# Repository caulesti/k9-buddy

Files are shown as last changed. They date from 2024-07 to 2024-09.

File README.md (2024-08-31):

# K9-Buddy
K9-Buddy is an open-source quadruped robot designed to promote STEAM education and provide a solid foundation for competing in robotics events. Notable for its low cost, K9-Buddy is accessible to both students and robotics enthusiasts.
<p align="center">
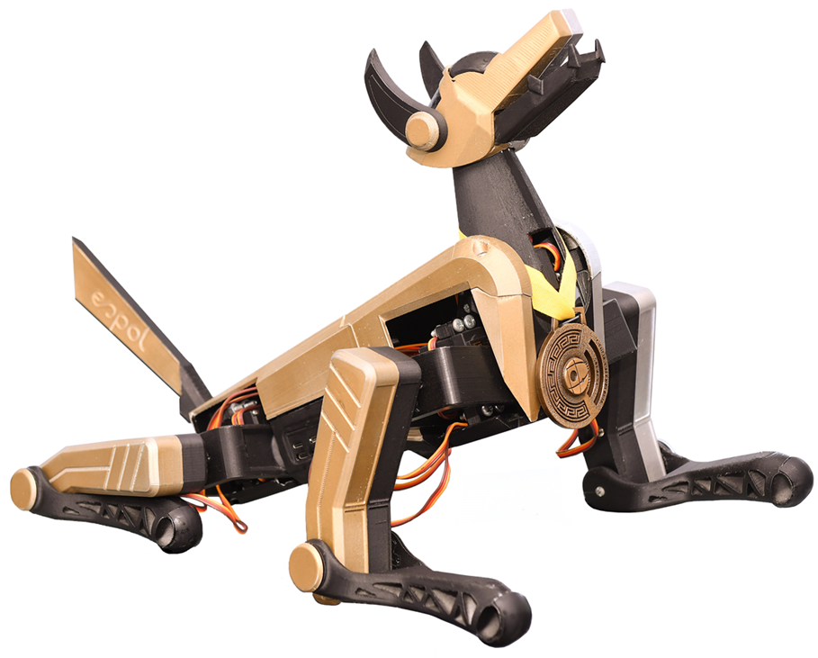
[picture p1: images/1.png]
K9-Buddy
  
</p>

### Environment Setup
1. Update the System
   
Open a terminal and run the following commands to update the package list and upgrade the installed packages to their latest versions:
```
sudo apt-get update
sudo apt-get upgrade
```
2. Install Python and Pip 
```
sudo apt-get install -y python3
sudo apt-get install -y python3-pip
```
3. Enable I2C and SSH services
   
Open the Raspberry Pi configuration menu
```
sudo raspi-config
```
Navigate to Interfacing Options > I2C and select Yes to enable I2C.
Navigate to Interfacing Options > SSH and select Yes to enable SSH.
Restart the Raspberry Pi to apply the changes:
```
sudo reboot
```
4. Install Additional Packages
   
Open a terminal and run the following commands:
```
# Install python-smbus and i2c-tools
sudo apt-get install -y python3-smbus
sudo apt-get install -y i2c-tools

# Verify the I2C connection
sudo i2cdetect -y 1

# Install Adafruit CircuitPython ServoKit
sudo pip3 install adafruit-circuitpython-servokit
```

### Usage
1. Cloning the Repository
```
git clone https://github.com/caulesti/k9-buddy.git
```
2. Grant permissions to the script
```
chmod +x k9-buddy/software/k9_buddy.py
```
3. Execution
```
python3 k9-buddy/software/k9_buddy.py
```

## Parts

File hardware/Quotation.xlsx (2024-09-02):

Component | Reference Supplier | Quantity | Unit price | Total price | Link
PiSugar S Plus | Amazon | 1 | $27.59 | $27.59 | https://www.amazon.com/-/es/dp/B097RCFHD2/ref=emc_b_5_t
Raspberry Pi 4 Model B | Amazon | 1 | $189.99 | $189.99
PCA9685 | Amazon | 1 | $20.74 | $20.74 | Amazon.com: 2327 - Raspberry Pi PWM Servo Hat Development Board : Electrónica (https://www.amazon.com/-/es/2327-Raspberry-Servo-Development-Board/dp/B00SI1SPHS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)
Step Down | Amazon | 1 | $10.99 | $10.99 | Amazon.com: ACEIRMC 3 unidades 20A 300W CC CV módulo de paso hacia abajo ajustable DC 6-40V a 1.2-36V regulador de voltaje Buck Converter módulo de fuente de alimentación de corriente constante : Electrónica (https://www.amazon.com/-/es/Aceirmc-convertidor-corriente-protecci%C3%B3n-cortocircuitos/dp/B099S2VQ2Q)
LiPo 2200mAh 7.4v | Amazon | 1 | $10.00 | $10.00 | Amazon.com: HRB 2 baterías 2S Lipo 7.4V 2200mAh RC LiPo con enchufe TR compatible con RC Car Truck Quadcopter Avión, Helicóptero Barco : Juguetes y Juegos (https://www.amazon.com/bater%C3%ADas-2200mAh-compatible-Quadcopter-Helic%C3%B3ptero/dp/B088QX6SXQ)
Servos MG90S | Amazon | 3 | $4.80 | $14.40 | Amazon.com: DiGiYes Paquete de 2 micro servomotores MG90S con engranaje de metal 9G para helicóptero, avión, barco, robot inteligente, controles de automóvil (ángulo de control de 360 grados) : Juguetes y Juegos (https://www.amazon.com/-/es/servomotores-MG90S-engranaje-helic%C3%B3ptero-inteligente/dp/B0BHYH7MQK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)
Servos MG995 | Amazon | 13 | $7.50 | $97.50 | https://www.amazon.com/-/es/servomotores-engranaje-velocidad-inteligente-helic%C3%B3ptero/dp/B0C3CWSCV1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
Total |  |  |  | $371.21

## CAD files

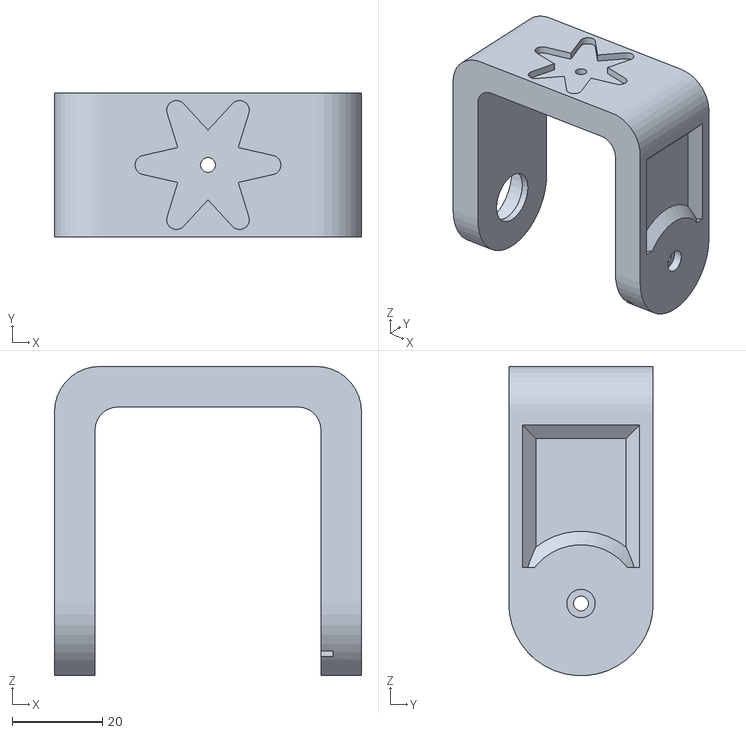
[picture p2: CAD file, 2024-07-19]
mechanical_design/stl_models/Hombro Izquierdo.STL
68.0 x 32.0 x 68.5

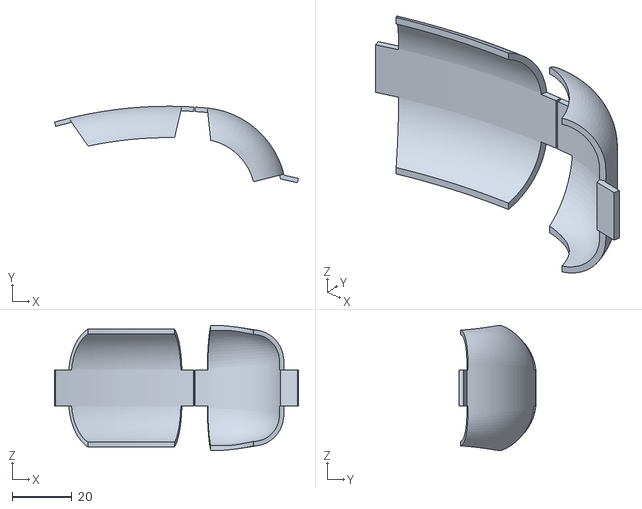
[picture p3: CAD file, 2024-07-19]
mechanical_design/stl_models/Visor.STL
81.7 x 25.6 x 41.8

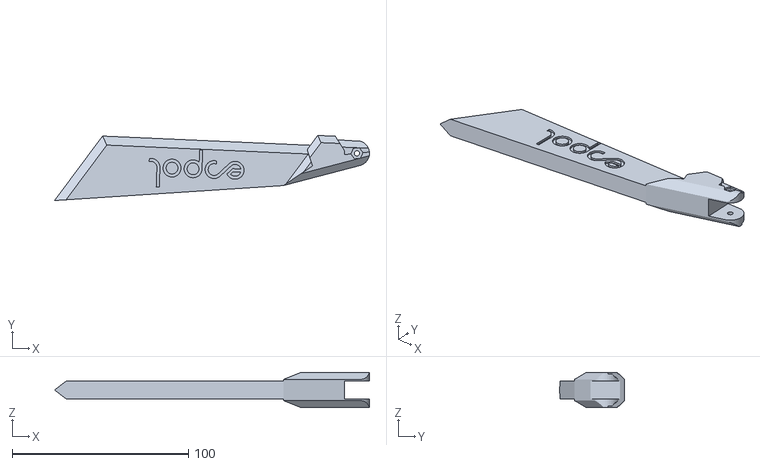
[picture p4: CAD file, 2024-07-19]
mechanical_design/stl_models/Cola.STL
178.9 x 37.0 x 20.0

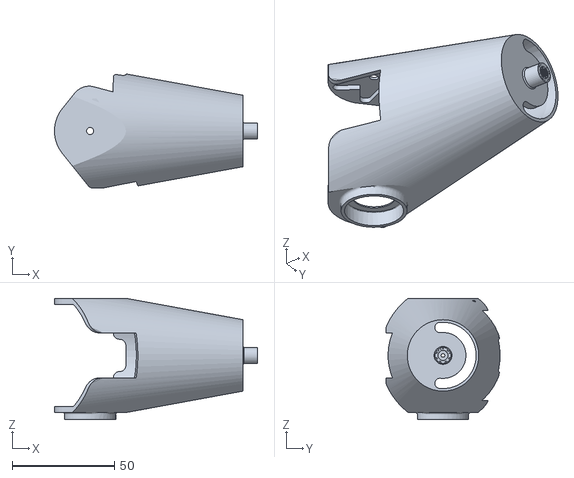
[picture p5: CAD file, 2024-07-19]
mechanical_design/stl_models/Cuello.STL
99.5 x 56.0 x 59.5

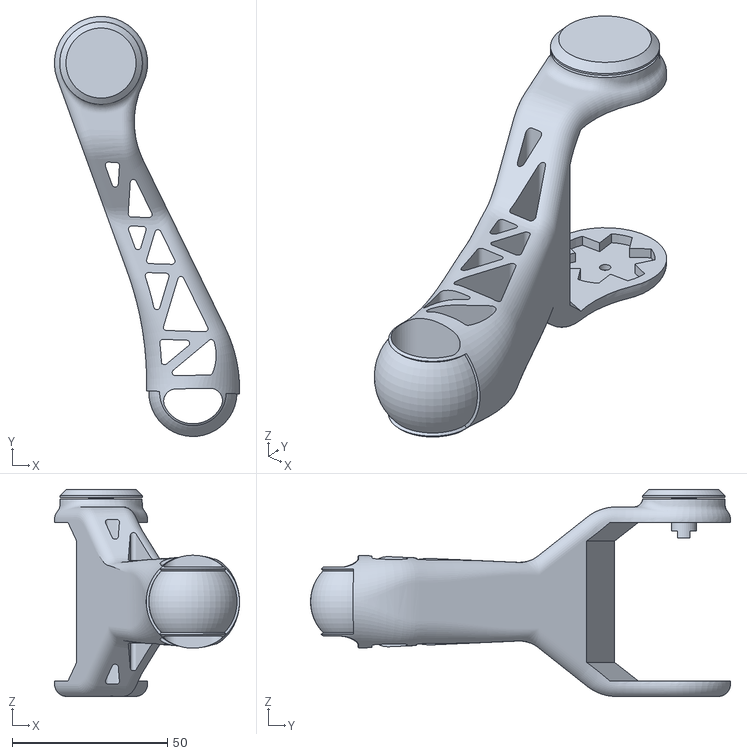
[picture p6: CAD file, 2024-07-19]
mechanical_design/stl_models/Pierna Inferior Derecha.STL
59.6 x 135.1 x 66.6

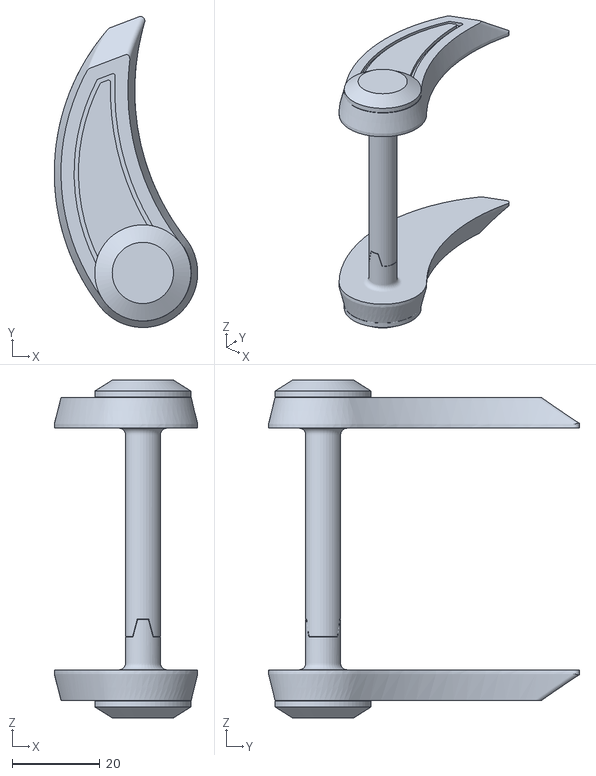
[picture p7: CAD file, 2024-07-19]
mechanical_design/stl_models/Orejas.STL
32.8 x 71.1 x 77.2

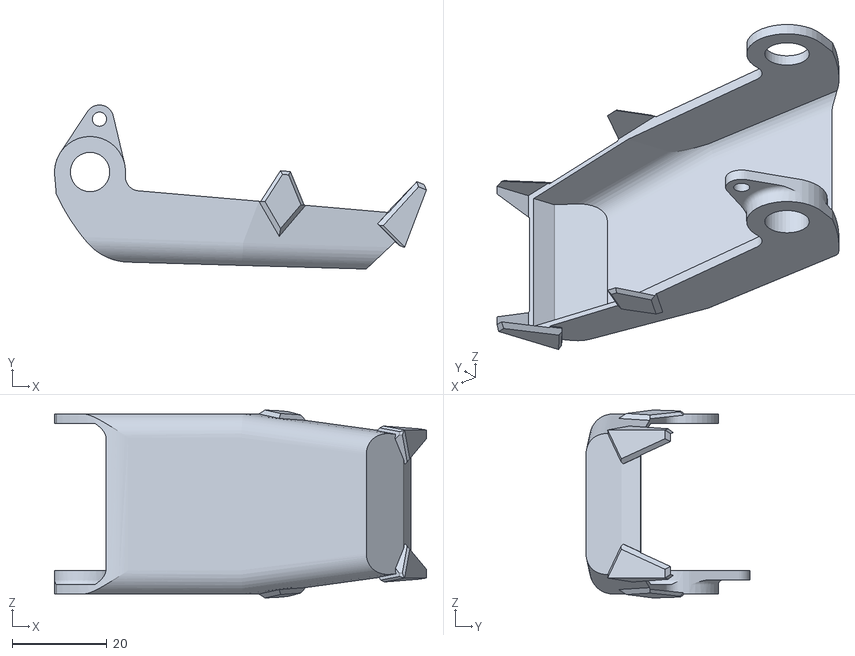
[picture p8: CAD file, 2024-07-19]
mechanical_design/stl_models/Mandibula.STL
78.5 x 34.6 x 39.7

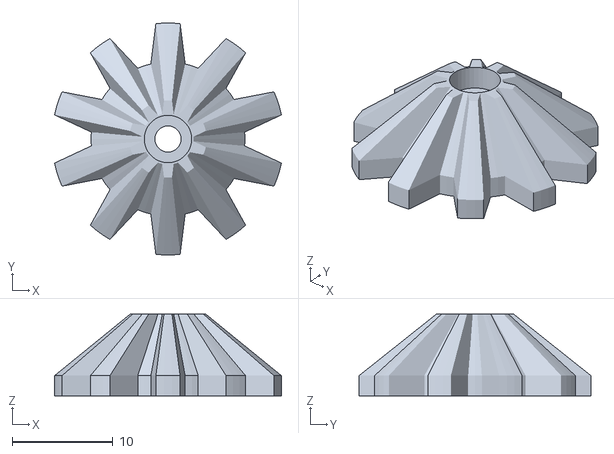
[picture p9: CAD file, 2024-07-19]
mechanical_design/stl_models/Engranaje Conico .STL
22.5 x 23.0 x 8.10

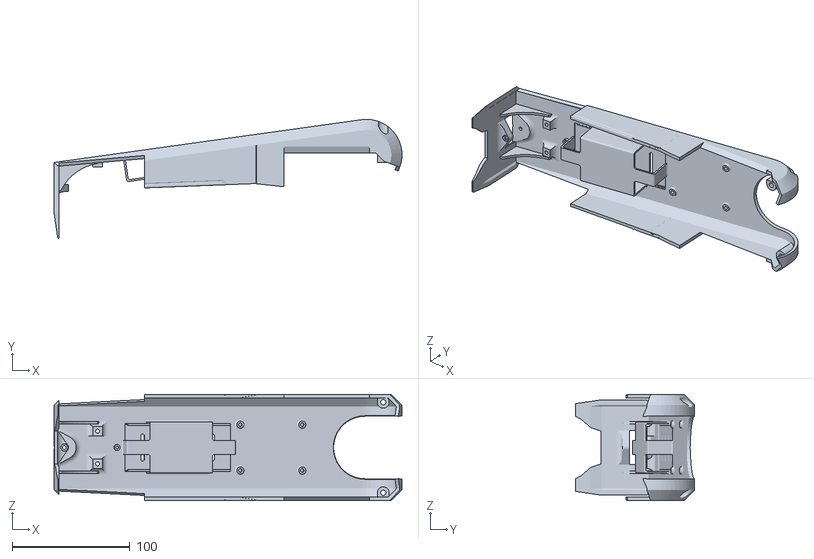
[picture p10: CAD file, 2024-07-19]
mechanical_design/stl_models/Cuerpo Superior.STL
295.0 x 101.1 x 90.0

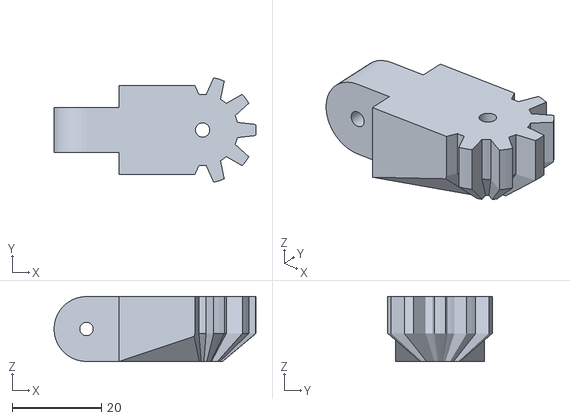
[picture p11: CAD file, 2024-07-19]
mechanical_design/stl_models/Union Cola.STL
45.4 x 23.5 x 14.6

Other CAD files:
mechanical_design/stl_models/Hombro Derecho.STL
mechanical_design/stl_models/Pierna Inferior Izquierda.STL

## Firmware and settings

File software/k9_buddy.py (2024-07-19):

#!/usr/bin/env python
# -*- coding: utf-8 -*-

# sudo apt-get install -y python-smbus
# sudo apt-get install -y i2c-tools
# sudo i2cdetect -y 1
# sudo pip3 install adafruit-circuitpython-servokit
  
#Libraries
import RPi.GPIO as GPIO
import time    
from adafruit_servokit import ServoKit 
import math  
#Constants
nbPCAServo=16
#Parameters
MIN_IMP  =[500, 500, 500, 500, 500, 500, 500, 500, 500, 500, 500, 500, 500, 500, 500, 500]
MAX_IMP  =[2500, 2500, 2500, 2500, 2500, 2500, 2500, 2500, 2500, 2500, 2500, 2500, 2500, 2500, 2500, 2500]
MIN_ANG  =[0, 0, 0, 0, 0, 0, 0, 0, 0, 0, 0, 0, 0, 0, 0, 0]
MAX_ANG  =[180, 180, 180, 180, 180, 180, 180, 180, 180, 180, 180, 180, 180, 180, 180, 180]
#Referencia
"""
Mi colocar el valor de la boca cerrada
Ce colocar el valor de la cabeza a la altura media
Cr colocar el valor de la cabeza centrada
"""
servoref =[60 ,80   ,-9  , 90 , 35  ,95  , 47   ,90 , 60  ,80  ,145  , 20 , 15 , 95 , 150, 130]
#PIN      [0  , 1   , 2  , 3  , 4   ,5   , 6    , 7 , 8   , 9  ,10   , 11 , 12  , 13 , 14 , 15 ]
#Nombres  [TD ,FD   , PD , Sc , RD  , HD , ED   , Cr, EI  , HI ,RI   , Mi , PI  , FI , Ce , TI ]
#Objects
pca = ServoKit(channels=16)
#Variables
pitch=0
roll=0
c=[0.0,0.0,0.0,0.0]
d=[0.0,0.0,0.0,0.0]
x=[0.0,0.0,0.0,0.0]
y=[0.0,0.0,0.0,0.0]
z=[0.0,0.0,0.0,0.0]
fo=[0.0,0.0,0.0,0.0]
fn=[0.0,0.0,0.0,0.0]
angle=[0,0,0,0,0,0,0,0,0,0,0,0,0,0,0,0]
#Modificar con las dimensiones del modelo físico
c[0] = c[1] = c[2] = c[3] = 186.81 #mm
fo[0] = fo[1] = fo[2] = fo[3] = 202.63 #mm
a = 95.0 #mm
b = 123.74 #mm
g = 78.50 #mm
# function main 
def main():
    #Setup
    #Para la pca9685
    for i in range(nbPCAServo):
        pca.servo[i].set_pulse_width_range(MIN_IMP[i] , MAX_IMP[i])
    time.sleep(0.010)
    x[0]=x[1]=x[2]=x[3]=0
    y[0]=y[1]=y[2]=y[3]=0
    #Para la rasp
    GPIO.setwarnings(False)
    GPIO.setmode(GPIO.BCM)
    try:
        #Rutina de baile
        thriller()
        time.sleep(7/6)
        theLazySong()
        time.sleep(19/15)
        whoLetTheDogsOut()
        time.sleep(62/15)
        shaky()
        time.sleep(89/30)
        OppaGangnamStyle()
        time.sleep(0.8)
        ladyGaga()
        time.sleep(1)
        aullar(5)
        time.sleep(1.2)
        risa(0.1)
    except(KeyboardInterrupt):
        print("Programa terminado por el usuario")
        GPIO.cleanup()
#Funcion para mantener la posicion
def holdPosition():
    for i in range(nbPCAServo):
        #print("Send angle {} to Servo {}".format(angle[i],i))
        pca.servo[i].angle = angle[i]
        time.sleep(0.001)
#Funcion donde se implementa cinematica inversa
def IK():
    A=[0.0,0.0,0.0,0.0]
    B=[0.0,0.0,0.0,0.0]
    C=[0.0,0.0,0.0,0.0]
    D=[0.0,0.0,0.0,0.0]
    E=[0.0,0.0,0.0,0.0]
    s=[0.0,0.0,0.0,0.0]
    thetaX=[0.0,0.0,0.0,0.0]
    thetaY=[0.0,0.0,0.0,0.0]
    
    for n in range(4):
        if pitch>=0:
            if n==1 or n==3:
                thetaX[n] = math.atan2(x[n]+ 155*(1 - math.cos((pitch * math.pi) / 180)) , c[n])
                d[n] = ((c[n] - z[n]) + 155 * math.sin((pitch*math.pi)/180)) / math.cos(thetaX[n])
                fo[n] = math.sqrt(pow(g,2)+pow(c[n],2))
                fn[n] = math.sqrt(pow(g,2)+pow(d[n],2))
                thetaY[n] = math.atan2(math.sin((90+math.atan2(g, c[n])*y[n])/fn[n]),(pow(fo[n],2)+pow(fn[n],2)-pow(y[n],2))/(2*fo[n]*fn[n]))
            if n==0 or n==2:
                thetaX[n] = math.atan2(x[n]- 155*(1 - math.cos((pitch*math.pi)/180)) , c[n])
                d[n] = ((c[n] - z[n]) - 155 * math.sin((pitch*math.pi)/180)) / math.cos(thetaX[n])
                fo[n] = math.sqrt(pow(g,2)+pow(c[n],2))
                fn[n] = math.sqrt(pow(g,2)+pow(d[n],2))
                thetaY[n] = math.atan2(math.sin((90+math.atan2(g, c[n])*y[n])/fn[n]),(pow(fo[n],2)+pow(fn[n],2)-pow(y[n],2))/(2*fo[n]*fn[n]))
        else:
            if n == 0 or n == 2:
                s[n] = x[n] + 155*(1 - math.cos((pitch*math.pi)/180))
                thetaX[n] = math.atan2(s[n], c[n])
                d[n] = ((c[n] - z[n]) - 155 * math.sin((pitch*math.pi)/180)) / math.cos(thetaX[n])
                fo[n] = math.sqrt(pow(g,2)+pow(c[n],2))
                fn[n] = math.sqrt(pow(g,2)+pow(d[n],2))
                thetaY[n] = math.atan2(math.sin((90+math.atan2(g, c[n])*y[n])/fn[n]),(pow(fo[n],2)+pow(fn[n],2)-pow(y[n],2))/(2*fo[n]*fn[n]))
            if n == 1 or n == 3:
                s[n] = x[n] - 155*(1 - math.cos((pitch*math.pi)/180))
                thetaX[n] = math.atan2(s[n], c[n])
                d[n] = ((c[n] - z[n]) + 155 * math.sin((pitch*math.pi)/180)) / math.cos(thetaX[n])
                fo[n] = math.sqrt(pow(g,2)+pow(c[n],2))
                fn[n] = math.sqrt(pow(g,2)+pow(d[n],2))
                thetaY[n] = math.atan2(math.sin((90+math.atan2(g, c[n])*y[n])/fn[n]),(pow(fo[n],2)+pow(fn[n],2)-pow(y[n],2))/(2*fo[n]*fn[n]))
    for n in range(4):
        A[n] = math.acos((pow(b, 2) + pow(d[n], 2) - pow(a, 2)) / (2 * b * d[n]))
        B[n] = math.acos((pow(a, 2) + pow(d[n], 2) - pow(b, 2)) / (2 * a * d[n]))
        C[n] = math.acos((pow(a, 2) + pow(b, 2) - pow(d[n], 2)) / (2 * a * b))
        D[n] = 90 - ((C[n] * 180) / math.pi)
        E[n] = math.acos((pow(g,2) + pow(fn[n],2) - pow(d[n],2))/(2 * g * fn[n]))
    for i in range(16):
        if i == 0:
            if C[0] >= math.pi / 2:
                angle[i] = servoref[i] + abs(D[0])
            else:
                angle[i] = servoref[i] - abs(D[0])
        elif i == 1:
            angle[i] = servoref[i] - ((B[0] * 180) / math.pi) + ((thetaX[0] * 180) / math.pi)
        elif i == 2:
            angle[i] = servoref[i] + ((E[0] * 180) / math.pi) + ((thetaY[0] * 180) / math.pi)
        elif i == 4:
            if C[1] >= math.pi / 2:
                angle[i] = servoref[i] + abs(D[1])
            else:
                angle[i] = servoref[i] - abs(D[1])
        elif i == 5:
            angle[i] = servoref[i] - ((B[1] * 180) / math.pi) + ((thetaX[1] * 180) / math.pi)
        elif i == 6:
            angle[i] = servoref[i] + ((E[1] * 180) / math.pi) - ((thetaY[1] * 180) / math.pi)
        elif i == 8:
            angle[i] = servoref[i] + ((E[3] * 180) / math.pi) - ((thetaY[3] * 180) / math.pi)
        elif i == 9:
            angle[i] = servoref[i] + ((B[3] * 180) / math.pi) - ((thetaX[3] * 180) / math.pi)
        elif i == 10:
            if C[3] >= math.pi / 2:
                angle[i] = servoref[i] - abs(D[3])
            else:
                angle[i] = servoref[i] + abs(D[3])
        elif i == 12:
            angle[i] = servoref[i] + ((E[2] * 180) / math.pi) + ((thetaY[2] * 180) / math.pi)
        elif i == 13:
            angle[i] = servoref[i] + ((B[2] * 180) / math.pi) - ((thetaX[2] * 180) / math.pi)
        elif i == 15:
            if C[2] >= math.pi / 2:
                angle[i] = servoref[i] - abs(D[2])
            else:
                angle[i] = servoref[i] + abs(D[2])
        else:
            angle[i] = servoref[i]
"""Funciones de movimiento"""
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
